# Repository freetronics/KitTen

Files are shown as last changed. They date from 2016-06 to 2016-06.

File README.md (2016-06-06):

Freetronics KitTen
==================
Copyright 2010-2013 Freetronics Pty Ltd  
Freetronics site:  www.freetronics.com  
Freetronics email: info@freetronics.com  

A fully-featured Arduino-compatible board in kit form. Includes a
voltage regulator and extensive filtering, plus a prototyping area.

Features:

 * Prototyping area
 * Overlay guide where you need it (both top and bottom)
 * D13 pin works for everything thanks to FET isolation
 * RX pin biased
 * Mounting holes and power pads
 * R3 (revision 3) Arduino header format

More information is available at:

  http://www.freetronics.com/kitten

INSTALLATION
------------
The design is saved as an EAGLE project. EAGLE PCB design software is
available from www.cadsoftusa.com free for non-commercial use. To use
this project download it and place the directory containing these files
into the "eagle" directory on your computer. Then open EAGLE and
navigate to Projects -> eagle -> KitTen.

DISTRIBUTION
------------
The specific terms of distribution of this project are governed by the
license referenced below.

LICENSE
-------
This work is licensed under the
Creative Commons Attribution-Share Alike License.  
To view a copy of this license, visit

  http://creativecommons.org/licenses/by-sa/3.0/  
  http://creativecommons.org/licenses/by-sa/3.0/legalcode

or send a letter to

  Creative Commons  
  171 Second Street, Suite 300  
  San Francisco  
  California, 94105  
  USA

The "license" folder within this repository also contains copies of the
licences referenced above.

CREDITS
-------
The KitTen was designed by Jonathan Oxer (jon@freetronics.com) and Marc
Alexander (marc@freetronics.com) based on previous work by the Arduino
team and various Freeduino variants including the Diavolino.

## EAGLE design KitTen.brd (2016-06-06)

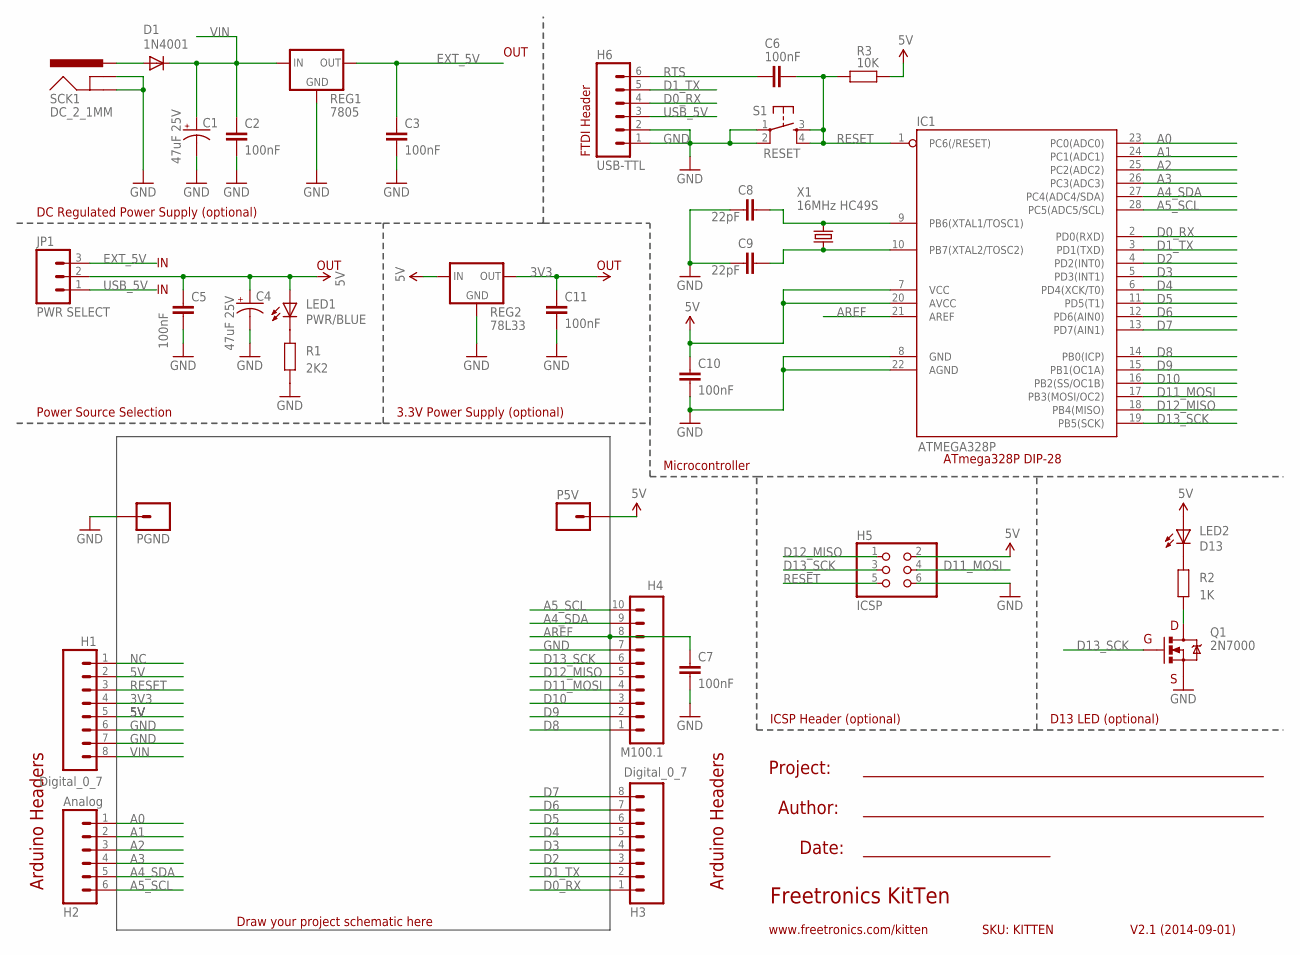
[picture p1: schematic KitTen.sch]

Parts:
C1, C4: 47uF 25V; CPOL-RADIAL-10UF-25V
C2, C3, C5, C6, C7, C10, C11: 100nF; CAP-PTH-SMALL
C8, C9: 22pF; CAP-PTH-SMALL
D1: 1N4001; DIODE-1N4001
H1, H3: Digital_0_7; 1X08
H2: Analog; 1X06
H4: M100.1; 1X10
H5: ICSP; 2X03
H6: USB-TTL; 1X06
IC1: ATMEGA328P; DIL28-3
JP1: PWR SELECT; 1X03
LED1: PWR/BLUE; LED3MM
LED2: D13; LED3MM
P5V: M01SMD; LUXEON-PAD
PGND: M01SMD; LUXEON-PAD
Q1: 2N7000; TO92
R1: 2K2; AXIAL-0.3
R2: 1K; AXIAL-0.3
R3: 10K; AXIAL-0.3
REG1: 7805; 78XXL
REG2: 78L33; TO92
S1: RESET; TACTILE-PTH
SCK1: DC_2_1MM; POWER_JACK_PTH
X1: 16MHz HC49S; HC49U-V

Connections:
3V3: C11.1, H1.4, REG2.1 (OUT)
5V: C4.1 (+), C5.1, C10.1, H1.2, H1.5, H5.2, IC1.7 (VCC), IC1.20 (AVCC), JP1.2, LED1.A, LED2.A, P5V.P$1, R3.P$2 (2), REG2.3 (IN)
A0: H2.1, IC1.23 (PC0(ADC0))
A1: H2.2, IC1.24 (PC1(ADC1))
A2: H2.3, IC1.25 (PC2(ADC2))
A3: H2.4, IC1.26 (PC3(ADC3))
A4_SDA: H2.5, H4.9, IC1.27 (PC4(ADC4/SDA))
A5_SCL: H2.6, H4.10, IC1.28 (PC5(ADC5/SCL))
AREF: C7.1, H4.8, IC1.21 (AREF)
D0_RX: H3.1, H6.4, IC1.2 (PD0(RXD))
D1_TX: H3.2, H6.5, IC1.3 (PD1(TXD))
D2: H3.3, IC1.4 (PD2(INT0))
D3: H3.4, IC1.5 (PD3(INT1))
D4: H3.5, IC1.6 (PD4(XCK/T0))
D5: H3.6, IC1.11 (PD5(T1))
D6: H3.7, IC1.12 (PD6(AIN0))
D7: H3.8, IC1.13 (PD7(AIN1))
D8: H4.1, IC1.14 (PB0(ICP))
D9: H4.2, IC1.15 (PB1(OC1A))
D10: H4.3, IC1.16 (PB2(SS/OC1B))
D11_MOSI: H4.4, H5.4, IC1.17 (PB3(MOSI/OC2))
D12_MISO: H4.5, H5.1, IC1.18 (PB4(MISO))
D13_SCK: H4.6, H5.3, IC1.19 (PB5(SCK)), Q1.2 (G)
EXT_5V: C3.1, JP1.3, REG1.OUT
GND: C1.2 (-), C2.2, C3.2, C4.2 (-), C5.2, C7.2, C8.1, C9.1, C10.2, C11.2, H1.6, H1.7, H4.7, H5.6, H6.1, H6.2, IC1.8 (GND), IC1.22 (AGND), PGND.P$1, Q1.1 (S), R1.P$1 (1), REG1.GND, REG2.2 (GND), S1.1, S1.2, SCK1.GND, SCK1.GNDBREAK
unnamed: LED2.K (C), R2.P$2 (2)
unnamed: C8.2, IC1.9 (PB6(XTAL1/TOSC1)), X1.2
unnamed: Q1.3 (D), R2.P$1 (1)
unnamed: C9.2, IC1.10 (PB7(XTAL2/TOSC2)), X1.1
unnamed: D1.A, SCK1.PWR
unnamed: LED1.K (C), R1.P$2 (2)
NC: H1.1
RESET: C6.2, H1.3, H5.5, IC1.1 (PC6(/RESET)), R3.P$1 (1), S1.3, S1.4
RTS: C6.1, H6.6
USB_5V: H6.3, JP1.1
VIN: C1.1 (+), C2.1, D1.C, H1.8, REG1.IN

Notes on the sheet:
Draw your project schematic here
Freetronics KitTen
V2.1 (2014-09-01)
SKU: KITTEN
www.freetronics.com/kitten
DC Regulated Power Supply (optional)
ATmega328P DIP-28
Power Source Selection
3.3V Power Supply (optional)
Arduino Headers
Project:
Date:
ICSP Header (optional)
D13 LED (optional)
Microcontroller
OUT
FTDI Header
Author:

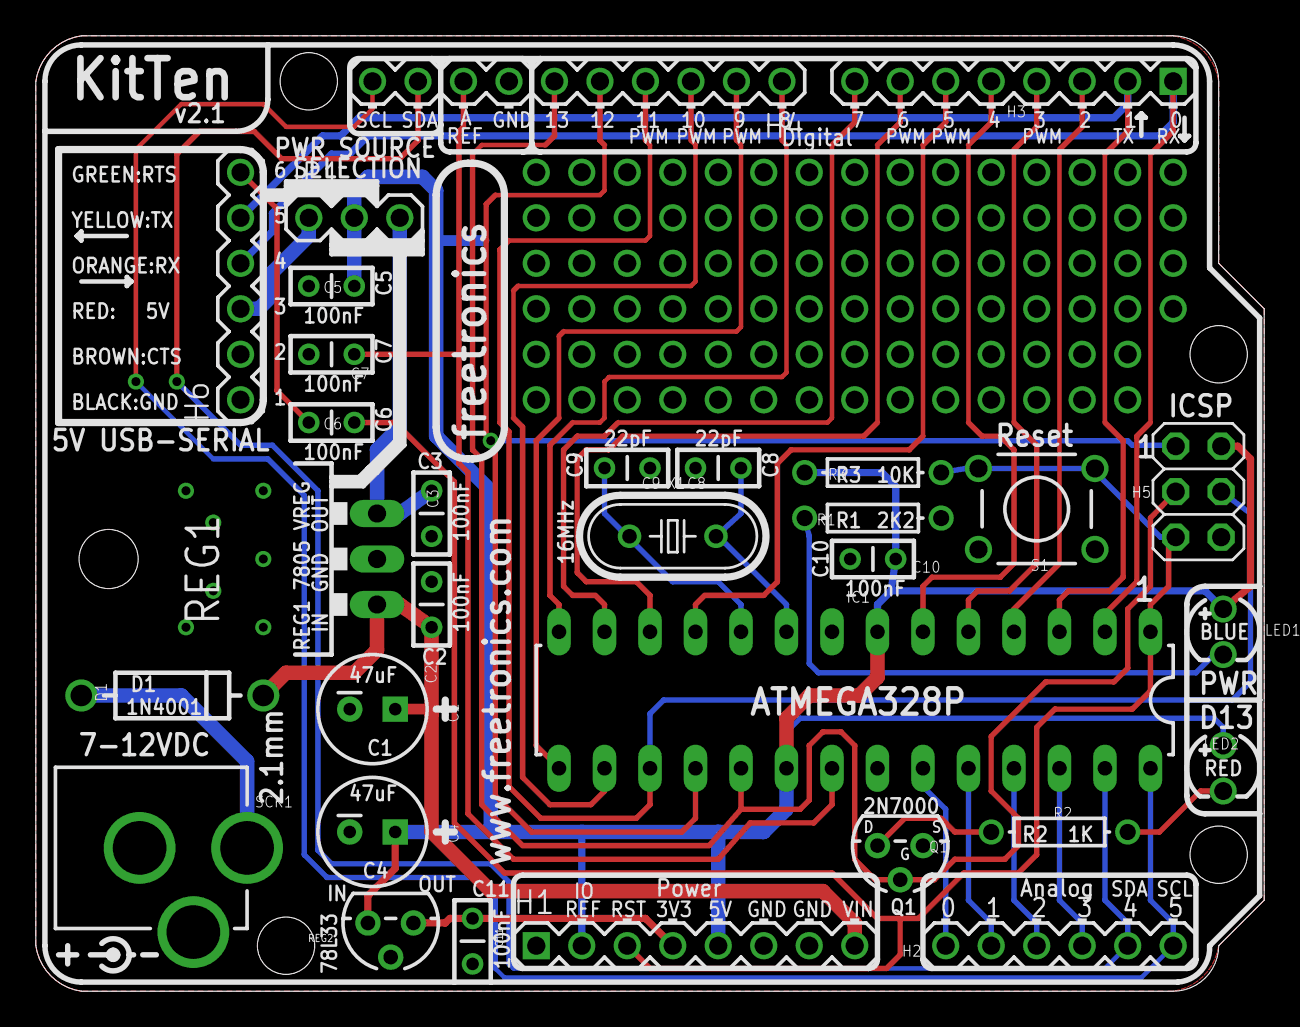
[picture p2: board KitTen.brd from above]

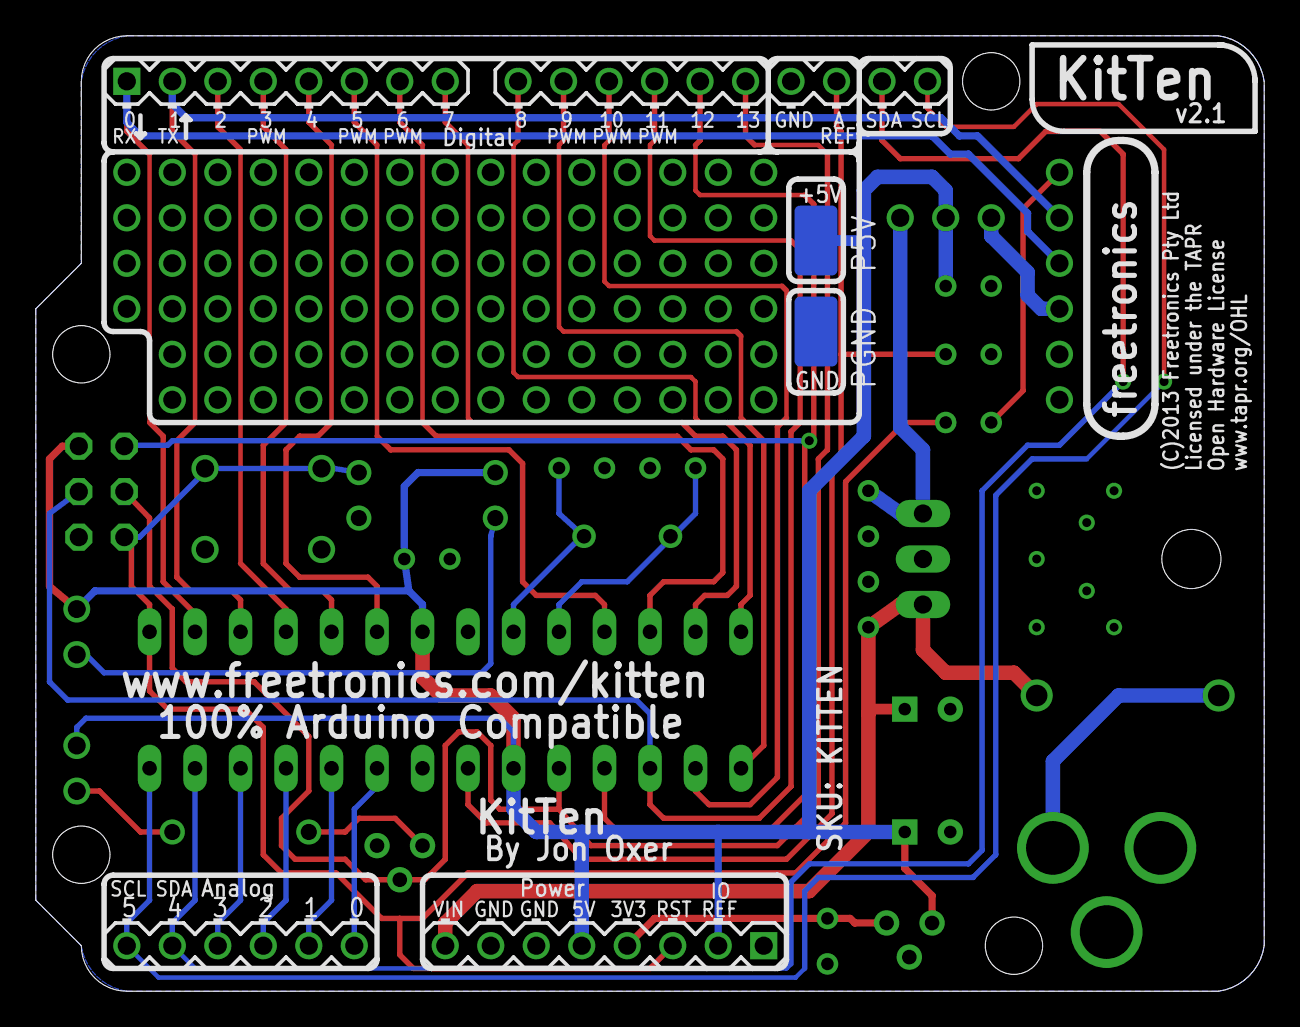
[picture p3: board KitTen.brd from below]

Board: 2 copper layers, 68.6 x 53.3 mm, 33 parts (2 on the bottom side), 35 nets.

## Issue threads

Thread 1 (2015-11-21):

Missing 'docs' folder in this repo.

SalvorinFex, 2015-11-21:
I read this in the readme.md

"The "docs" folder within this repository includes a handy copy of the schematic in PDF format, images of the pcb, and our Getting Started guide that ships with each board."

However, I do not see a "docs" folder.

jonoxer, 2016-06-06:
This project was originally derived from the "Eleven" board project, so the README was copied over and never updated. Sorry about that. I've just edited the README to remove the reference to those non-existent files, and also pushed other updates to the board itself.

Closed 2016-06-06.

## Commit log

2010-09-01 Initial import of rough project concept
    [KitTen.brd, KitTen.sch]
2010-09-02 More SMT parts replacement and schematic rearrangement
    [KitTen.brd, KitTen.sch]
2010-09-02 Moving parts around to get a basic layout
    [KitTen.brd, KitTen.sch]
2010-09-02 Moved parts around, trying to find a neat layout
    [KitTen.brd]
2010-09-03 Routing getting close to finished, major elements in place
    [KitTen.brd]
2010-09-03 Tweaking PCB layout
    [KitTen.brd]
2010-09-04 Added 3.3V supply; major overhaul of schematic; reduced traces in proto area to 10thou
    [KitTen.brd, KitTen.sch]
2010-09-07 Moved 3.3V reg onto the board, moved other things around
    [KitTen.brd]
2010-09-07 Routing tweaks. Getting closer, but still ugly around the MOSFET in particular
    [KitTen.brd]
2010-09-08 Routing tweaks and assembly overlay
    [KitTen.brd, KitTen.sch]
2010-09-08 Fixed MOSFET pinout and added part IDs to overlay
    [KitTen.brd, KitTen.sch]
2010-09-08 Fixed MOSFET part number
    [KitTen.brd, KitTen.sch]
2010-09-08 Moved cap polarity indicators
    [KitTen.brd]
2010-09-11 Made a big mess by moving stuff around
    [KitTen.brd]
2010-09-26 Nearly final routing and overlay, still some cleanups to go
    [KitTen.brd]
2010-09-28 Removed 100K pulldown on RX, and moved 47uF to after power select jumper
    [KitTen.sch]
2010-09-28 More positioning, routing, and overlay tweaks
    [KitTen.brd]
2010-09-28 More routing cleanups. Hopefully final now
    [KitTen.brd]
2010-09-29 Improved overlay and added thermal relief to voltage reg
    [KitTen.brd]
2010-09-29 Made via positions under vreg neater
    [KitTen.brd]
2010-10-04 Tweak location of MOSFET to provide more space near header markings
    [KitTen.brd]
2013-02-13 Updated to R3 header format
    [KitTen.brd, KitTen.sch]
2014-09-01 Improved silkscreen for v1.0 release
    [KitTen.brd]
2014-09-01 Improved silkscreen for v2.0 release
    [KitTen.brd]
2016-06-06 Improved silkscreen, removed docs reference from README, bumped version for 2.1 release
    [KitTen.brd, KitTen.sch]

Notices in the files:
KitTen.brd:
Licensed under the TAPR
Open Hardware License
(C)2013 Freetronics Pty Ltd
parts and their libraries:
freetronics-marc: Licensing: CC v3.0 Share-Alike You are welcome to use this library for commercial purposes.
